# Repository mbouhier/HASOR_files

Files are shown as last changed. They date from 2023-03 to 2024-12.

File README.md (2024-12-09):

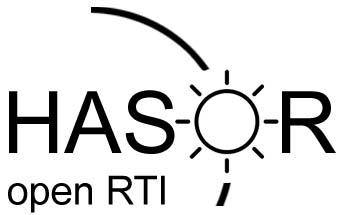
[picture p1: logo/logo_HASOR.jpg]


# HASOR - OpenRTI Arduino and Hardware Repository

Welcome to the official GitHub repository for the Arduino code and hardware design files related to the HASOR - OpenRTI device. This repository contains the necessary files for programming the Arduino, 3D printing components using STL files, and laser cutting using vector files.

## Arduino Code

The `/arduino sketch` directory contains the Arduino code for the HASOR - OpenRTI device. This code is responsible for controlling and coordinating the various functions and features of the device. Follow the instructions below to upload the code to your Arduino:

1. Open the Arduino IDE.
2. Navigate to File > Open and select the `controleur_arduino_hasor` directory previously copied on your computer.
3. Connect your Arduino mega board to your computer.
4. Select the appropriate board and port in the Arduino IDE.
5. Click the "Upload" button to transfer the code to the Arduino.

## 3D Printed Parts (STL Files)

The `/3D printing` directory houses the STL files for the 3D-printed components of the HASOR - OpenRTI device. These files are ready for use with your 3D printer. Feel free to customize the printing parameters based on your specific 3D printer and material. Please check the HASOR - OpenRTI device website for details about printing parameters.

## Laser Cutting (Vector Files)

In the `/laser cutting` directory, you'll find vector files for laser cutting the parts of the HASOR - OpenRTI device. Drawing are done for 3mm thick material. These files are provided in a format compatible with your preferred laser cutting software. Ensure that you adjust the settings such as  cutting and engraving power according to your laser cutter specifications.

## Contribution

Contributions and improvements are encouraged! If you have enhancements or fixes to propose, please follow these steps:

1. **Fork** the repository.
2. Create a new branch for your feature or bug fix.
3. Make the necessary changes.
4. Submit a **Pull Request** with a clear description of the changes made.

## Issues and Suggestions

Report issues or share your suggestions by opening an **Issue**. Your feedback is valuable for the continuous improvement of the HASOR - OpenRTI device.

## License

This project is licensed under the CC BY-NV-ND 4.0 licence - see the LICENSE description for more details.

Thank you for contributing to the HASOR - OpenRTI project!

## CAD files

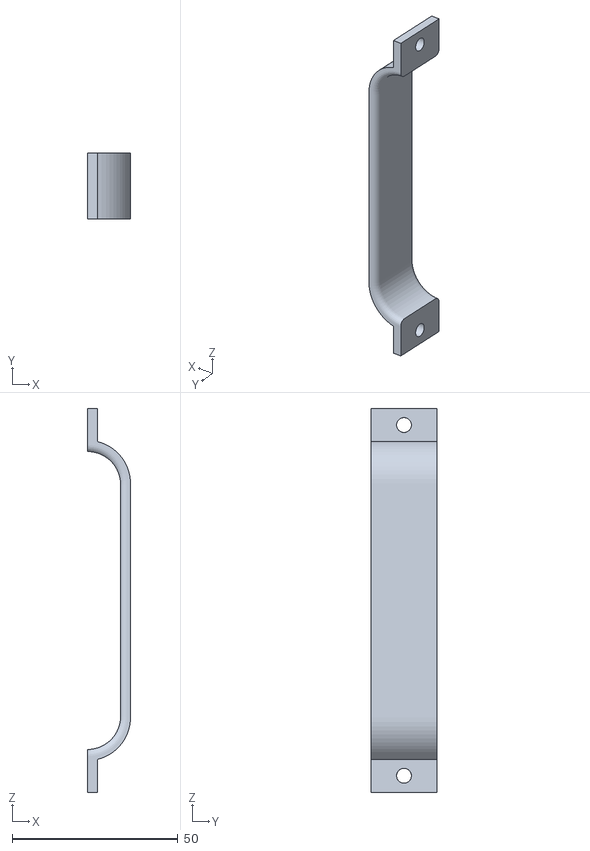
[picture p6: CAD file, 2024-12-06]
3D printing/inventor files/guide_nappe_led_v2.stl
13.0 x 20.0 x 116.0

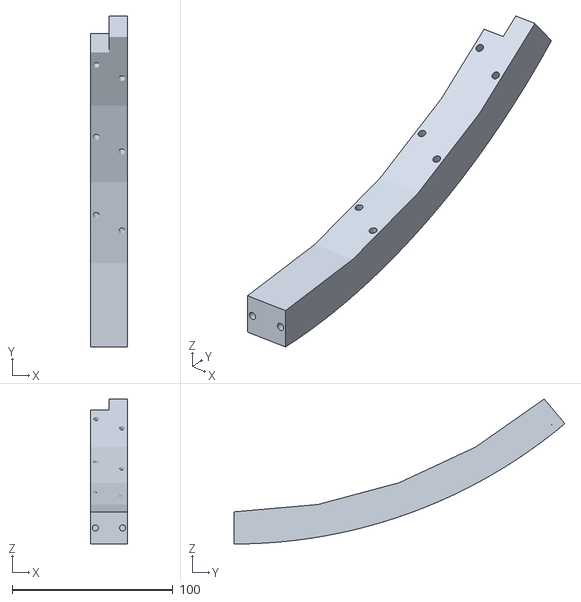
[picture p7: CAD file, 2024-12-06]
3D printing/stl files/grande_fourche_partieA.stl
23.0 x 205.7 x 90.2

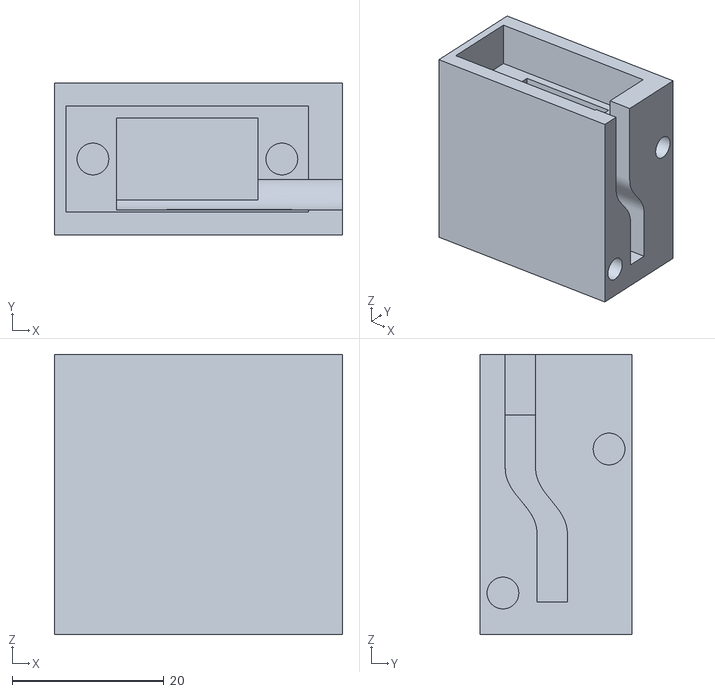
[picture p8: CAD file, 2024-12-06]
3D printing/stl files/sub_db9_block v1.stl
38.0 x 20.0 x 37.0

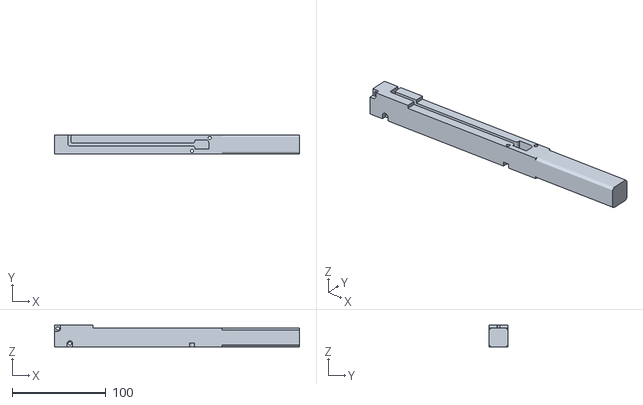
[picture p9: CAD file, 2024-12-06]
3D printing/stl files/bas_de_fourche_gros_bloc_grand.stl
262.0 x 20.0 x 23.0

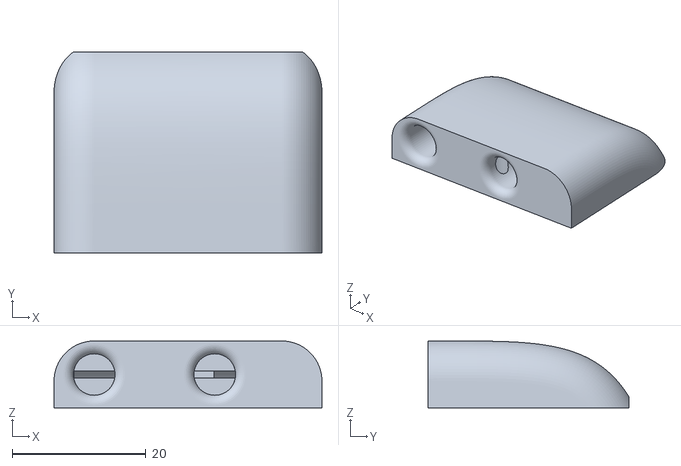
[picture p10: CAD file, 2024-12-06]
3D printing/stl files/ir_plug v5.stl
40.0 x 30.0 x 10.0

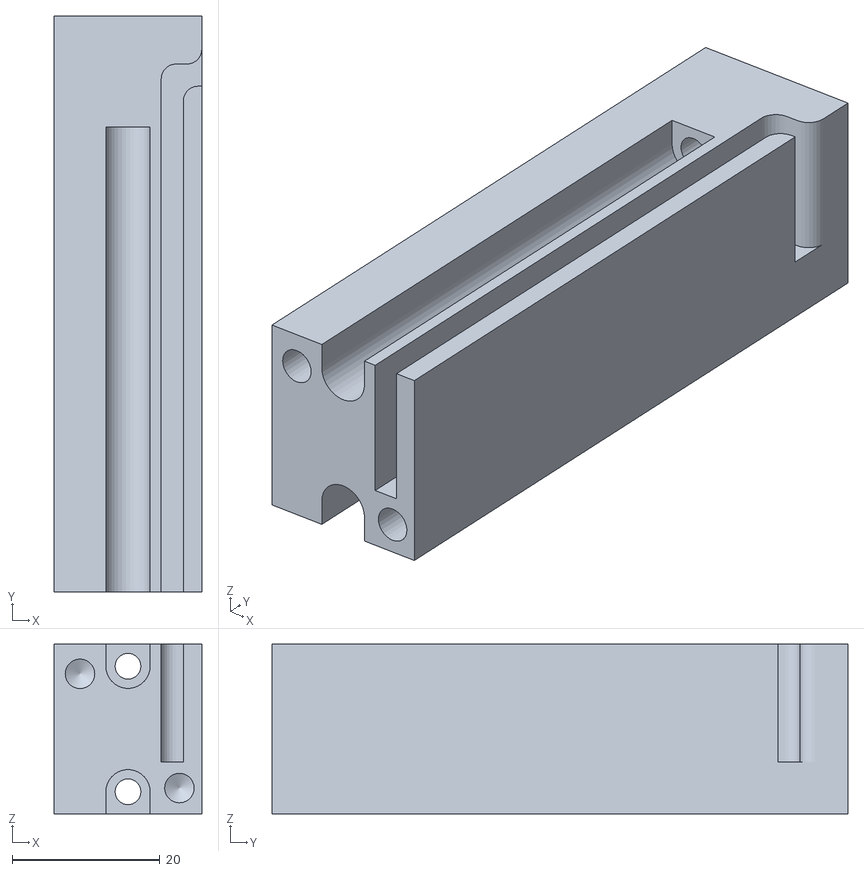
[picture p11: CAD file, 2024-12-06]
3D printing/stl files/fourche_jonction_bas_haut_grand.stl
20.0 x 78.0 x 23.0

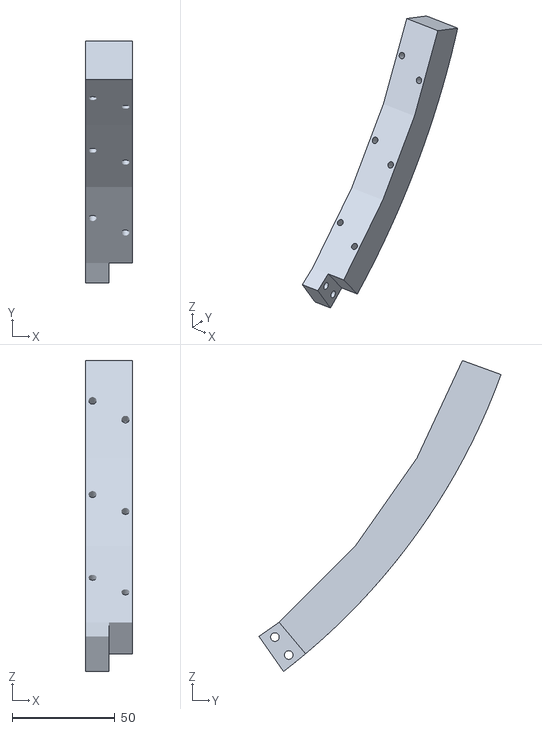
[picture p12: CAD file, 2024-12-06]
3D printing/stl files/grande_fourche_partieB.stl
23.0 x 117.7 x 151.1

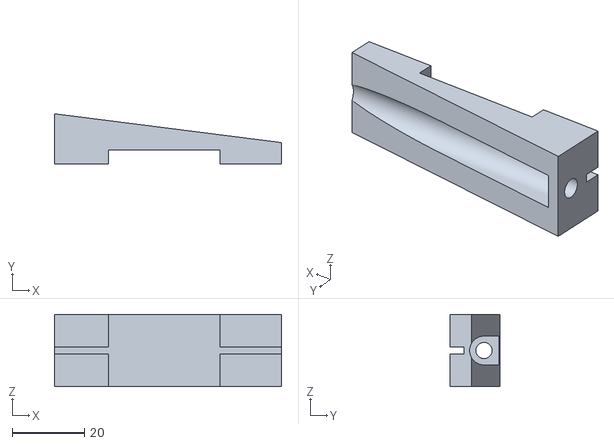
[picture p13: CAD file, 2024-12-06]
3D printing/stl files/support_lcd_v4.stl
63.0 x 14.0 x 20.0

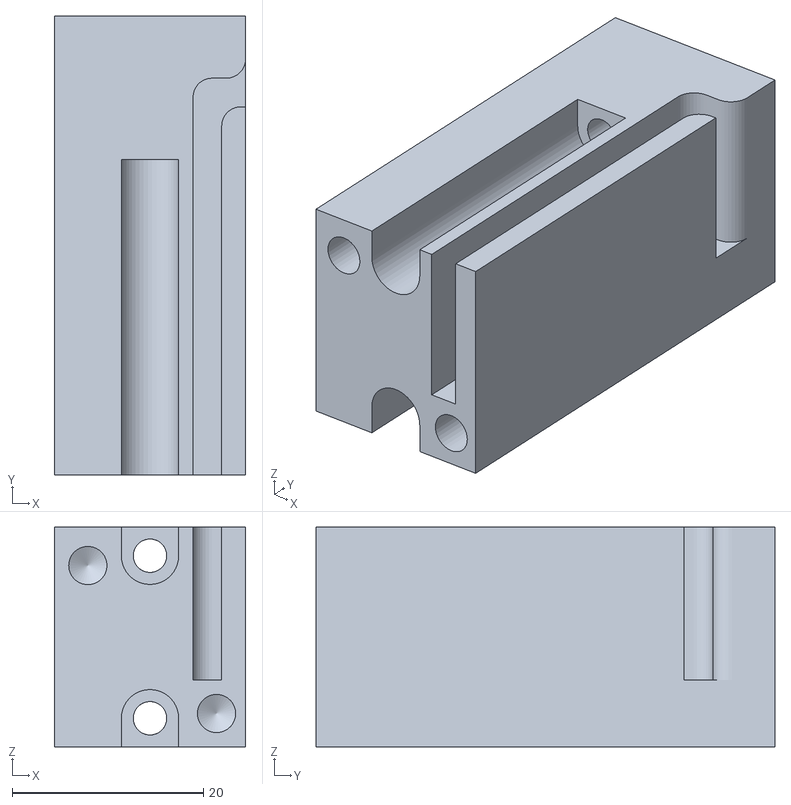
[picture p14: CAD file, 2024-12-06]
3D printing/stl files/fourche_jonction_bas_haut_petit.stl
20.0 x 48.0 x 23.0

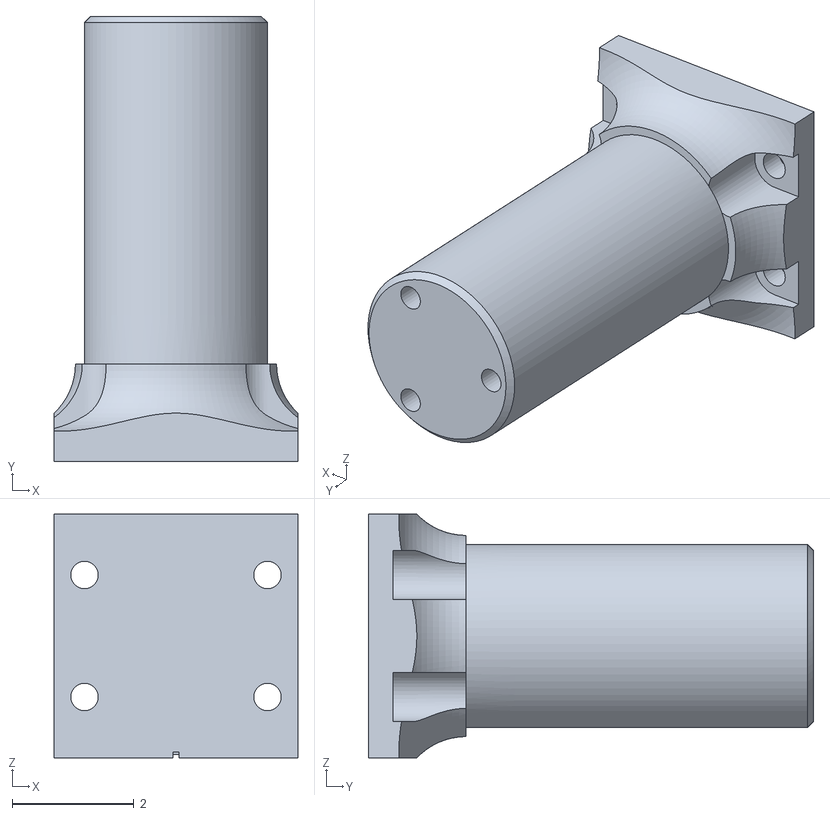
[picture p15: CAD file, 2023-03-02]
3D printing/stl files/arbre_central_4040_rev11.stl
4.00 x 7.30 x 4.00

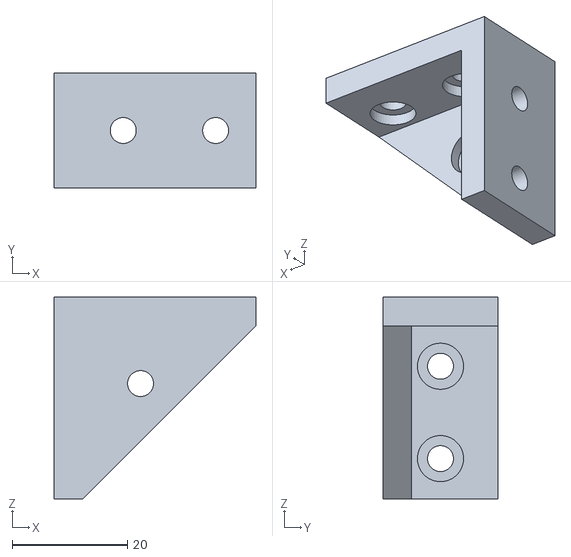
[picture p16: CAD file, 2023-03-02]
3D printing/stl files/angle_90_profile_2020.stl
35.0 x 20.0 x 35.0

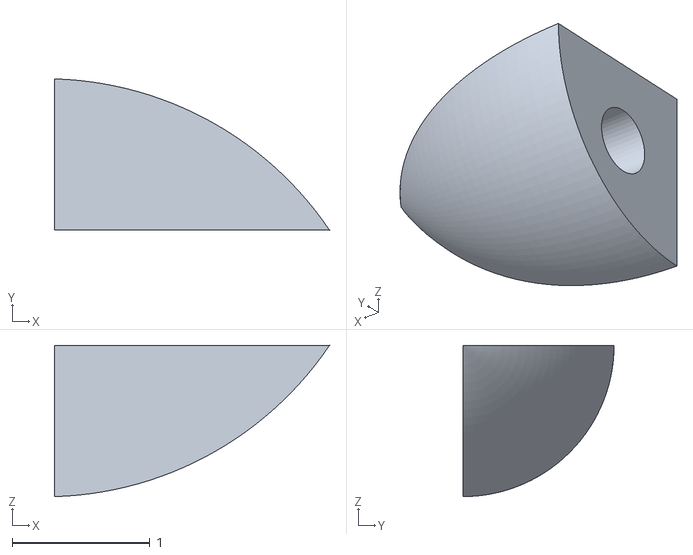
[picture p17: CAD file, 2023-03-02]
3D printing/stl files/corner_insert.stl
2.00 x 1.10 x 1.10

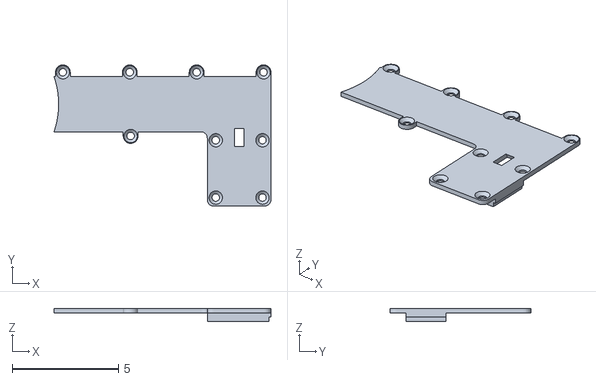
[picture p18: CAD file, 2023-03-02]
3D printing/stl files/support_fourche_partie2_capot.stl
10.2 x 6.65 x 0.61

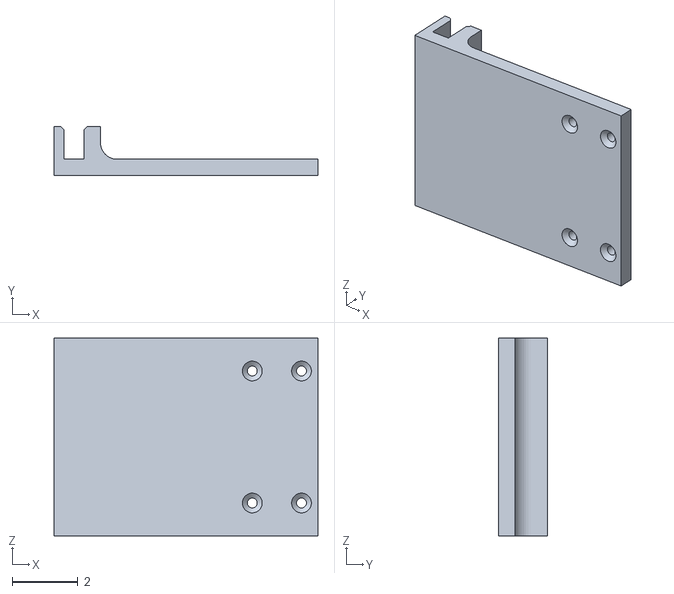
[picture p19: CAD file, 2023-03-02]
3D printing/stl files/stabilisateur.stl
8.00 x 1.50 x 6.00

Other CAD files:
3D printing/stl files/bloceur_alim.stl
3D printing/stl files/end_stop_40mm_v3.stl
3D printing/stl files/support_fourche_principal_simplifie4.stl
3D printing/inventor files/angle_90_profile_2020.ipt
3D printing/inventor files/arbre_central_4040_rev11.ipt
3D printing/inventor files/bas_de_fourche_gros_bloc.ipt
3D printing/inventor files/bloceur_alim.ipt
3D printing/inventor files/cache_nappe_cote_v2.ipt
3D printing/inventor files/corner_insert.ipt
3D printing/inventor files/end_stop_40mm_v2.ipt
3D printing/inventor files/end_stop_40mm_v3.ipt
3D printing/inventor files/end_stop_plug_v3.ipt
3D printing/inventor files/espaceur_20mm_v3.ipt
3D printing/inventor files/espaceur_20mm_v4.ipt
3D printing/inventor files/fourche_jonction_bas_haut.ipt
3D printing/inventor files/fourche_v2_sans_radiateurs.ipt
3D printing/inventor files/guide_nappe_led.ipt
3D printing/inventor files/stabilisateur.ipt
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

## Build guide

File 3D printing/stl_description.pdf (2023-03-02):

# HASOR RTI – STL parts

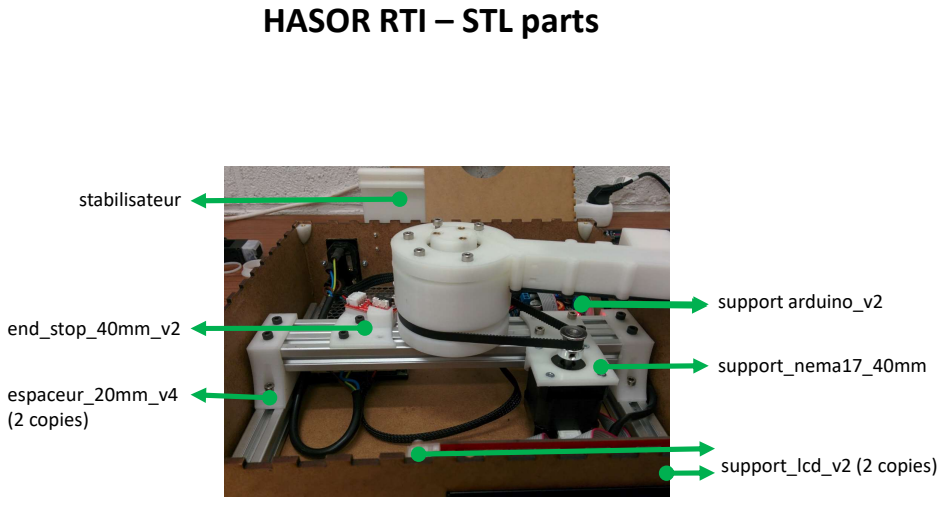
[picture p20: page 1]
support_lcd_v2 (2 copies); espaceur_20mm_v4 (2 copies); support arduino_v2; support_nema17_40mm; stabilisateur; end_stop_40mm_v2

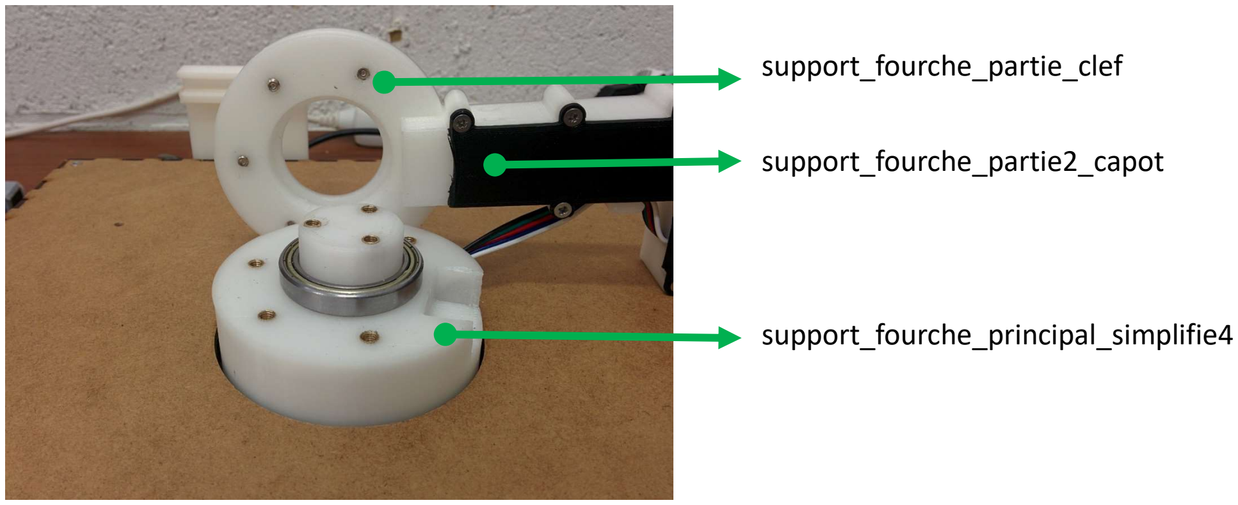
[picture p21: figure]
support_fourche_partie_clef; support_fourche_partie2_capot; support_fourche_principal_simplifie4

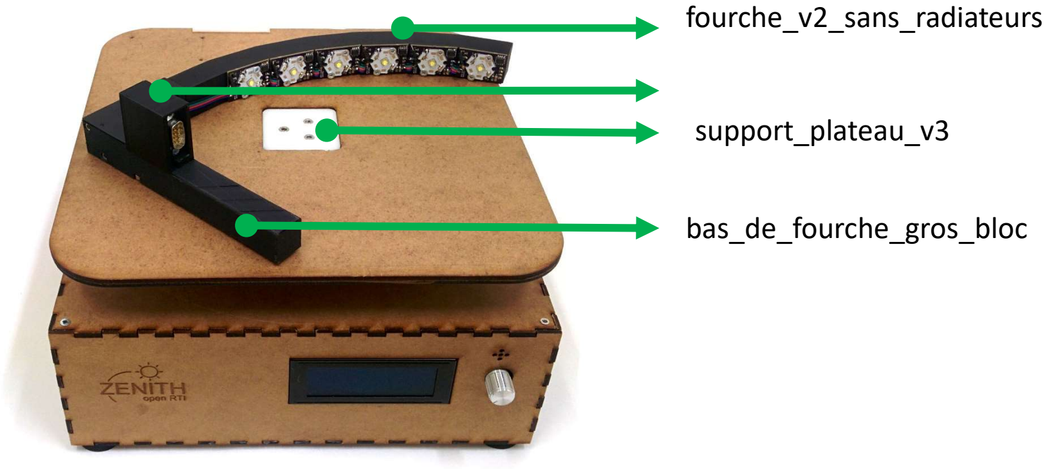
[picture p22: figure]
support_plateau_v3; bas_de_fourche_gros_bloc; fourche_v2_sans_radiateurs

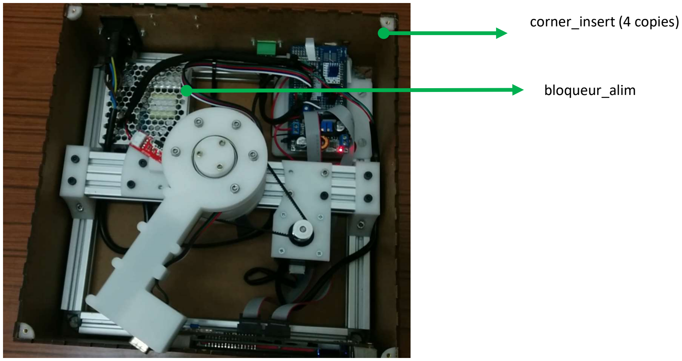
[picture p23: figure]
corner_insert (4 copies); bloqueur_alim

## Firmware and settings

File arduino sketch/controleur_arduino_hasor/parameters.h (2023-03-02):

// *********************************************************************
// *************          LOAD/SAVE PARAMETERS         *****************
// *********************************************************************
#ifndef PARAMETERS_H
#define PARAMETERS_H

#include <EEPROM.h>

#define  DEFAULT_PRESET_ID              0
#define  DEFAULT_SHUTTER_TYPE           SHUTTER_TYPE_RELAY
#define  DEFAULT_MOTOR_SPEED            500
#define  DEFAULT_STABILIZATION_DELAY    1000
#define  DEFAULT_SHUTTER_DURATION       500
#define  DEFAULT_LED_ON_DURATION        1000
#define  DEFAULT_SNAP_DELAY             1000
#define  DEFAULT_STEPS_COUNT            12
#define  DEFAULT_MIN_POLAR_POSITION     0
#define  DEFAULT_MAX_POLAR_POSITION     1.0
#define  DEFAULT_IR_SIGNAL_ID           0
#define  DEFAULT_IR_SIGNAL              222
#define  DEFAULT_LED_MODULES_COUNT      LED_MODULES_COUNT
#define  DEFAULT_LED_COUNT_IN_MODULE    LED_COUNT_IN_MODULE
#define  DEFAULT_LAST_LED_WEIGHT        100
#define  DEFAULT_FIRST_LED_INDEX        0
#define  DEFAULT_MAX_LEDS_INTENSITY     1.
#define  DEFAULT_LED_WEIGHT             100


//Attention, pas de prise en compte dynamique des CONFIG_COUNT, MODULE_COUNT_MAX, LED_BY_MODULE_MAX pour l'initialisation (TODO)
//Initialiser avec {CONFIG_COUNT x {MODULE_COUNT_MAX*LED_BY_MODULE_MAX}}
#define  DEFAULT_LED_WEIGHTS_ARRAY      {{100,100,100,100,100,100,100},{100,100,100,100,100,100,100},{100,100,100,100,100,100,100},{100,100,100,100,100,100,100},{100,100,100,100,100,100,100},{100,100,100,100,100,100,100}}
//Initialiser avec {CONFIG_COUNT x 1.}                                   
#define  DEFAULT_MOTOR_SPEEDS_ARRAY     {1.,1.,1.,1.,1.,1.}
                                     

//class ZenithParametersClass{
//  private:

//  public:
//    void saveParametersInEeprom();
//    void loadParametersFromEeprom();
//}

void saveParametersInEeprom();
bool loadParametersFromEeprom();
byte isValidParameters();


//https://www.approxion.com/?p=24
float *default_motor_speeds_array();
byte *default_led_weights_array();


struct ZenithParameters{
  char parameters_version[4];
  byte preset_id;
  byte shutter_type;
  float motor_speeds[CONFIG_COUNT];
  long stabilization_delay;
  long shutter_duration;
  long led_on_duration;
  long snaps_delay;
  int steps_count;
  float min_polar_position;
  float max_polar_position;
  byte IR_signal_id;
  byte IR_Signal;
  long led_modules_count;
  long led_by_module;
  long last_led_weight;
  int first_led_index;
  float max_leds_intensity;
  byte leds_weights[CONFIG_COUNT][MODULE_COUNT_MAX*LED_BY_MODULE_MAX];//values from 0 to 100
  
} params = {
  PARAMETERS_VERSION,
  DEFAULT_PRESET_ID,
  DEFAULT_SHUTTER_TYPE,
  DEFAULT_MOTOR_SPEEDS_ARRAY,
  DEFAULT_STABILIZATION_DELAY,
  DEFAULT_SHUTTER_DURATION,
  DEFAULT_LED_ON_DURATION,
  DEFAULT_SNAP_DELAY,
  DEFAULT_STEPS_COUNT,
  DEFAULT_MIN_POLAR_POSITION,
  DEFAULT_MAX_POLAR_POSITION,
  DEFAULT_IR_SIGNAL_ID,
  DEFAULT_IR_SIGNAL,
  DEFAULT_LED_MODULES_COUNT,
  DEFAULT_LED_COUNT_IN_MODULE,
  DEFAULT_LAST_LED_WEIGHT,
  DEFAULT_FIRST_LED_INDEX,
  DEFAULT_MAX_LEDS_INTENSITY,
  DEFAULT_LED_WEIGHTS_ARRAY
};


void saveParametersInEeprom(){
  EEPROM.put(PARAMETERS_ADRESS + params.preset_id*sizeof(ZenithParameters), params);
  Serial.println(F("Parameters saved in eeprom"));
}


bool loadParametersFromEeprom(){
  //Check if parameters structure already exists in memory
  if(isValidParameters())
  {
    EEPROM.get(PARAMETERS_ADRESS + params.preset_id*sizeof(ZenithParameters), params);
    Serial.println(F("Parameters loaded from EEPROM"));
    return true;
  }
  else{
    Serial.println(F("Invalid parameters in eeprom"));
    return false;
  }
}

byte isValidParameters(){
  if (EEPROM.read(PARAMETERS_ADRESS + params.preset_id*sizeof(ZenithParameters) + 0) == PARAMETERS_VERSION[0] &&
      EEPROM.read(PARAMETERS_ADRESS + params.preset_id*sizeof(ZenithParameters) + 1) == PARAMETERS_VERSION[1] &&
      EEPROM.read(PARAMETERS_ADRESS + params.preset_id*sizeof(ZenithParameters) + 2) == PARAMETERS_VERSION[2]){
    return true;
  }
  else{
    return false;
  }
}
#endif

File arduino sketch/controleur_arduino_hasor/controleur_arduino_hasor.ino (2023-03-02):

// A4988 driver test routine
//http://www.instructables.com/id/Drive-a-Stepper-Motor-with-an-Arduino-and-a-A4988-/?ALLSTEPS

/*=============================================*/
/*              IMPORT LiBRARIES               */
/*=============================================*/
#include "elapsedMillis.h"

#include "configuration.h"
#include "parameters.h"
#include "stepper_control.h"
#include "lcd_panel.h"
#include "camera_shutter.h"
#include "led_modules.h"
#include "temperature_ctrl.h"
#include "acquisition_modes.h"
/*=============================================*/
/*       
/*=============================================*/



void setup() {
  Serial.begin(SERIAL_SPEED);
  while (!Serial); // wait for serial monitor to connect

  loadParametersFromEeprom();

  pinMode(PIN_INFO_LED, OUTPUT);
  digitalWrite(PIN_INFO_LED, HIGH);

  init_temperature_ctrl();
  init_lcd_panel();
  init_menu();

  motor.init(PIN_MC_ENABLE, PIN_MC_STEP, PIN_MC_DIR, PIN_SENSOR_ENDSWITCH);
  motor.setEnableSwitches(true, false);
  motor.max_position_in_step = STEPS_IN_TOTAL_TRAVEL;
  
  attachInterrupt(digitalPinToInterrupt(motor.pin_sensor_end_switch_left), motor_end_switch_left_ISR, CHANGE);

  
//  motor.init(PIN_MC_ENABLE, PIN_MC_STEP, PIN_MC_DIR, PIN_SENSOR_ENDSWITCH);
//  motor.set_speed(400);
//  attachInterrupt(digitalPinToInterrupt(motor.pin_sensor_end_switch_left), motor_end_switch_left_ISR, CHANGE);


  
  //init_stepper_control();
  shutter.init(params);
  init_led_modules();
}



/*=============================================*/
/*         MISCELLANEOUS METHODS               */
/*=============================================*/


/*=============================================*/
/*              MAIN LOOP                      */
/*=============================================*/
void loop() {
  
  loop_menu();
  shutter.loop();
  acquisition.loop();
  led_modules_loop();
  motor.loop();
  
}

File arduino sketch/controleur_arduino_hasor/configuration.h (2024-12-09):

#define DEBUG 1


#define PIN_INFO_LED 13


#define LED_MODULES_COUNT 6
#define LED_COUNT_IN_MODULE 1
#define LEDS_DATA_PIN 9
#define MODULE_COUNT_MAX 7L      //used to record values in epprom
#define LED_BY_MODULE_MAX 1L

//Chip controller the leds
#define LED_TYPE  WS2811//NEOPIXEL//WS2812B 
#define WIRING_TYPE_CHAIN 0   //all module in same way
#define WIRING_TYPE_ZIG_ZAG 1 //modules alternate
#define WIRING_TYPE WIRING_TYPE_CHAIN
#define INVERT_LED_LOGIC 1

#define SPLASH_SCREEN_DURATION 1000
  
#define PIN_SHUTTER_IR_LED 3 // HACK 15/11/24 anciennement 42, mise sur la broche du endsgtop -X inutilisée
#define PIN_SHUTTER_RELAY 5
#define PIN_FOCUS_RELAY 4

#define PIN_MC_ENABLE 24
#define PIN_MC_STEP 26
#define PIN_MC_DIR 28

#define MC_SPEED 1000
#define STEPS_IN_TOTAL_TRAVEL 8240//1030 setRangeInStep//TMC2208 works by default at 1/16 step
#define PIN_SENSOR_ENDSWITCH 2
#define SERIAL_SPEED 57600

#define CALIBRATION_TIMEOUT 5000
#define CALIBRATE_ON_STARTUP 1
#define PARAMETERS_VERSION "pv1" //Change this when modifiing params structure
#define PARAMETERS_ADRESS  32
#define CONFIG_COUNT 6 

#define RELAY_OPEN LOW
#define RELAY_CLOSED HIGH
#define SHUTTER_TYPE_RELAY 0
#define SHUTTER_TYPE_IR 1

#define IR_NIKON_ID 0
#define IR_CANON_ID 1
#define IR_CANONWLDC100_ID 2
#define IR_PENTAX_ID 3
#define IR_OLYMPUS_ID 4
#define IR_MINOLTA_ID 5
#define IR_SONY_ID 6
#define IR_CUSTOM_ID 7

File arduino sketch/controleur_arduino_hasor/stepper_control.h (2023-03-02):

/**
 * Zenith Open RTI
 * Copyright (C) 2017
**/

#define CLOCKWISE 0
#define ANTICLOCKWISE 1

#define END_SWITCH_REACHED  LOW /*sensor state when triggered*/

#define MOTOR_MAX_SPEED 4500//7000
#define MOTOR_SLOW_SPEED_COEFF 0.4
#define MOTOR_ACCELERATION 2000//3000

#define MOTOR_CALIBRATION_OK 1
#define MOTOR_CALIBRATION_TIMEOUT 7000

#define COARSE_INCREMENT_DURING_CALIBRATION 30
#define FINE_INCREMENT_DURING_CALIBRATION 1

#define MOTOR_ON   0
#define MOTOR_OFF  1

#define ENABLE_AUTOSLEEP 1
#define AUTOSLEEP_DELAY 10000

#include <AccelStepper.h>



/*=============================================*/
/*            VARIABLES DECLARATION            */
/*=============================================*/



class Motor{
  

  
  private:
    void _update_motor_position_counter(int, byte);
    void _reset_motor_position_counter();
    void _pulse_MC_driver();
    byte _is_destination_in_range(int);
    void _update_flags();
    void _reset_position_counter();
    byte _findSwitch(byte *, const byte, long *);
    void _checkAutosleep();
    byte _motor_state;

  public:
    void init(byte, byte, byte, byte);
    void stepNow(int, byte);
    void set_speed(long);
    void setNormalSpeedMode();
    void setSlowSpeedMode();
    void set_state(byte);
    void set_direction(byte);
    void setRangeInStep(long,long);
    void end_switch_left_ISR();
    void end_switch_right_ISR(); 
    byte findLeftSwitch();
    byte findRightSwitch();
    byte calibrate();
    void setEnableSwitches(boolean, boolean);
    void moveToRelativePosition(float);
    float getRelativePosition();
    void loop();

    
    int steps_in_complete_rotation;
    long position = 0; //ex int
    int destination = 0;
    byte direction = CLOCKWISE;
    long speed = MOTOR_MAX_SPEED;
    long start_time = millis(); //debut du mouvement
    long end_time = millis();   //fin du mouvement
    long last_step_time = millis();

    int min_position_in_step = 0;
    int max_position_in_step = 200; 
    
    byte destination_reached = false;
    volatile byte end_switch_left_state = !END_SWITCH_REACHED;
    volatile byte end_switch_right_state = !END_SWITCH_REACHED;
    byte pin_mc_enable;
    byte pin_mc_step;
    byte pin_mc_dir;
    byte pin_sensor_end_switch_left;
    byte pin_sensor_end_switch_right;
    boolean _left_switch_enable = false;
    boolean _right_switch_enable = false;
    long _offset_from_switch_in_step = 0; //if we whant to stop moving before endswitchs
    
    AccelStepper stepper;

} motor;

//A wrapper for ISR because attachInterrupt whant only non-member function
//http://arduino.stackexchange.com/questions/4862/attachinterrupt-in-a-library
void motor_end_switch_left_ISR(){
  motor.end_switch_left_ISR();
}
void motor_end_switch_right_ISR(){
  motor.end_switch_right_ISR();
}



void Motor::init(byte pin_mc_enable, byte pin_mc_step, byte pin_mc_dir, byte pin_sensor_end_switch_left){
  /*=============================================*/
  /*               DEFINE OUTPUTS                */
  /*=============================================*/
  pinMode(pin_mc_enable, OUTPUT);
  stepper = AccelStepper(AccelStepper::DRIVER, uint8_t(pin_mc_step), uint8_t(pin_mc_dir));
//  stepper.setEnablePin(pin_mc_enable);
//  stepper.enableOutputs();
  this->set_speed(long(MOTOR_MAX_SPEED*params.motor_speeds[params.preset_id]));

  /*=============================================*/
  /*               DEFINE INPUTS                 */
  /*=============================================*/
  pinMode(pin_sensor_end_switch_left,INPUT);
  //pinMode(pin_sensor_end_switch_right,INPUT);
  
  /*=============================================*/
  /*               INITIALISATION                */
  /*=============================================*/ 

  //Semble ne pas fonctionner quand placé ici
  //this->end_switch_left_ISR();
  //this->end_switch_right_ISR();

  
  //interrupt have to be attached outside
  //attachInterrupt(digitalPinToInterrupt(pin_sensor_end_switch_left), this->end_switch_left_ISR, CHANGE);
  //attachInterrupt(digitalPinToInterrupt(pin_sensor_end_switch_right), this->end_switch_right_ISR, CHANGE);
  
  this->pin_mc_enable = pin_mc_enable;
  this->pin_mc_step = pin_mc_step;
  this->pin_mc_dir = pin_mc_dir;
  this->pin_sensor_end_switch_left = pin_sensor_end_switch_left;
  //this->pin_sensor_end_switch_right = pin_sensor_end_switch_right;
}



/*=============================================*/
/*               MOTOR METHODS                 */
/*=============================================*/


void Motor::setEnableSwitches(boolean left_switch, boolean right_switch){
  this->_left_switch_enable  = left_switch;
  this->_right_switch_enable = right_switch;
}

void Motor::set_speed(long m_speed){
  this->speed = m_speed;
  stepper.setMaxSpeed(m_speed);
  stepper.setAcceleration(MOTOR_ACCELERATION);
}


void Motor::_checkAutosleep(){
  
  if(this->_motor_state == MOTOR_ON and ENABLE_AUTOSLEEP and this->destination_reached){
    if((millis() - this->end_time) > AUTOSLEEP_DELAY){
      if(DEBUG) Serial.println(F("Motor autosleep"));
      this->set_state(MOTOR_OFF);
    }
  }
  if(!this->destination_reached and this->_motor_state == MOTOR_OFF){
    this->set_state(MOTOR_ON);
  }
  
}

void Motor::loop(){
  this->_update_flags();

  this->_checkAutosleep();
  
  stepper.run();
}

void Motor::setRangeInStep(long min_step,long max_step){
  this->min_position_in_step = min_step;
  this->max_position_in_step = max_step;
}

void Motor::moveToRelativePosition(float pos){
  //Go from 0 to 1: where 1 is the maximum position of the motor

  long position_in_step = long(this->min_position_in_step + pos*(this->max_position_in_step - this->min_position_in_step));

//  char print_buffer[45];
//  Serial.println(pos);
//  Serial.println(this->min_position_in_step);
//  Serial.println(this->max_position_in_step);
//  sprintf(print_buffer,"Going to position %d.%02d (step %ld)", (int)pos, (int)(pos*100)%100, position_in_step);
//  Serial.println(print_buffer);

  this->stepper.moveTo(position_in_step);
}

float Motor::getRelativePosition(){

  float relative_position = 1.0*(this->stepper.currentPosition() - this->min_position_in_step) / (this->max_position_in_step - this->min_position_in_step);
  
  return relative_position;
}


void Motor::_reset_position_counter(){
  this->stepper.setCurrentPosition(0);
  this->_update_flags();
  Serial.print("Motor position reset");
}


void Motor::_update_flags(){
   if(this->stepper.distanceToGo()==0){
      if(!this->destination_reached){
        this->destination_reached = true;
        this->end_time = millis();
      }
   }
   else{
      this->destination_reached = false;
   }
}

void Motor::setNormalSpeedMode(){
  
  long m_speed  = long(MOTOR_MAX_SPEED*params.motor_speeds[params.preset_id]);
  
  Serial.print("setting Normal speed Mode:");
  Serial.println(m_speed);
  
  this->set_speed(m_speed);
}
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

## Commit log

2024-12-06 update of some stl parts
    [bas_de_fourche_gros_bloc_grand.stl, fourche_jonction_bas_haut_grand.stl, fourche_jonction_bas_haut_petit.stl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]
2024-12-09 update lasercutting files
2024-12-09 updates in menu and IR trigger
    [configuration.h]
